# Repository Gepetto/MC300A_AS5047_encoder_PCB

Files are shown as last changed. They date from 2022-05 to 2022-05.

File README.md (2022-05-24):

# MC300_AS5047_encoder_PCB
This is a PCB support for a AS5047 magnetic encoder to replace MC300A control board on myactuator RMD-X actuators.



https://ams.com/en/as5047p
https://www.myactuator.com/_files/ugd/cab28a_d12405ad9d114c308658ca2bf5e42c5b.pdf

# Authors 
* Amine El Hamdaoui
* Jerome Manhes
* Thomas Flayols

LAAS CNRS

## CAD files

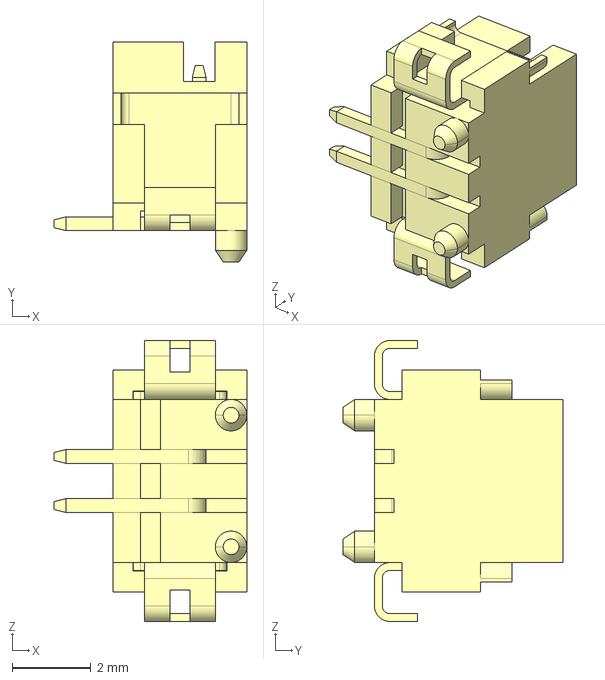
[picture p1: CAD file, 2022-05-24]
encoder_PCB/3D Models/DF13-2P-1.25V-75---3DModel-STEP-1.STEP
4.90 x 5.60 x 7.15 mm

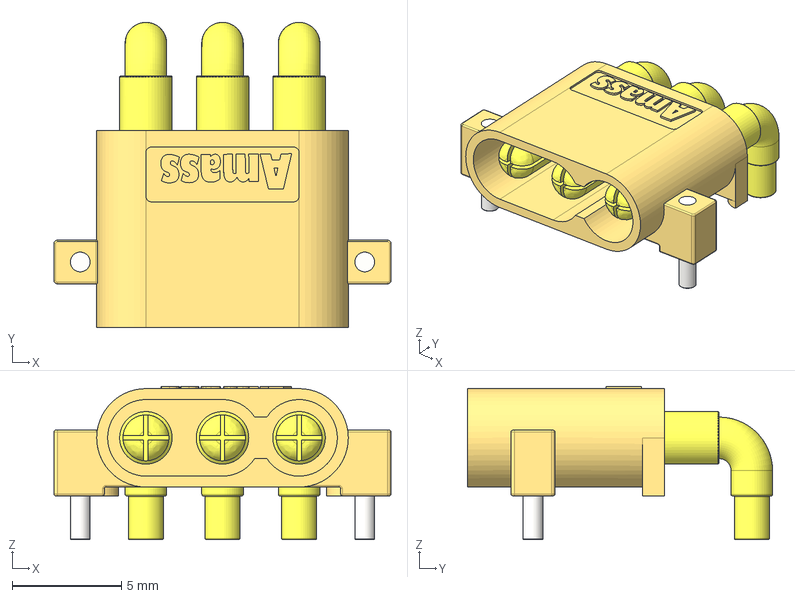
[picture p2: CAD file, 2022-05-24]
encoder_PCB/symbols_blueprints_3D_backup/MR30PW-M v2.step
15.4 x 13.9 x 7.00 mm
PCB Pins
Pin 2 x 3

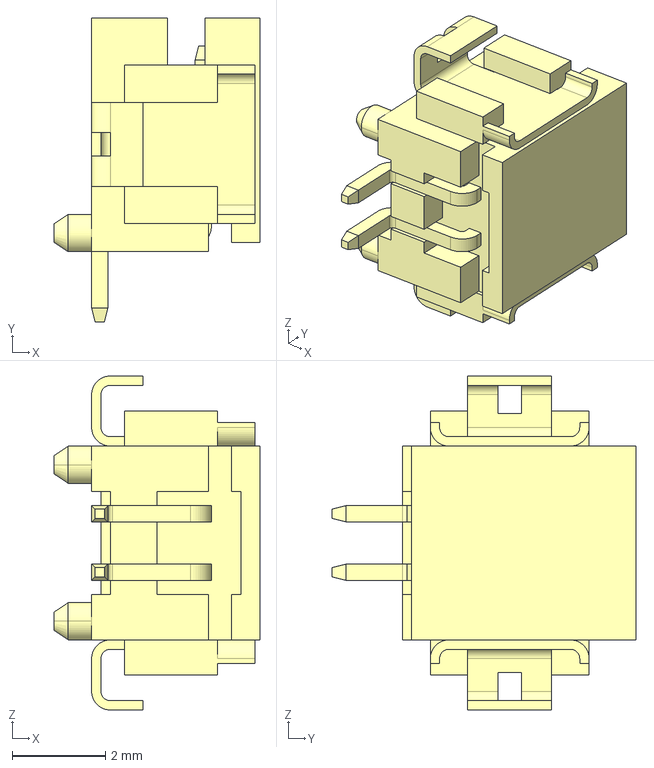
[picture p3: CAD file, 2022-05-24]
encoder_PCB/3D Models/DF13-2P-1.25H-75---3DModel-STEP-1.STEP
4.40 x 6.50 x 7.15 mm

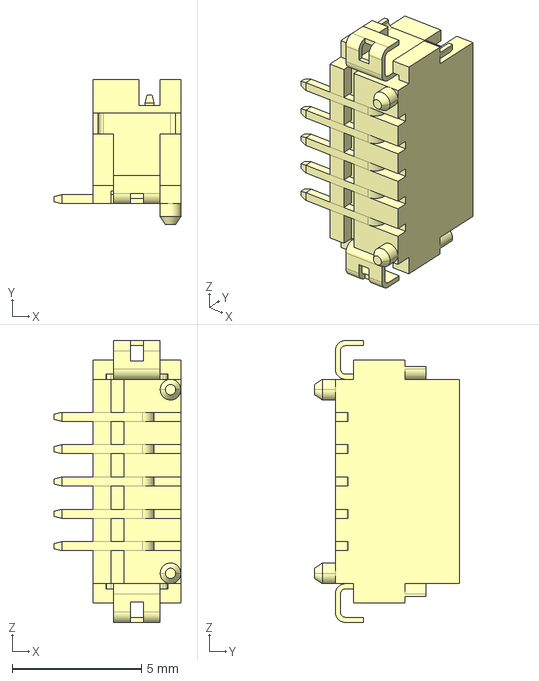
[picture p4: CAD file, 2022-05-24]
encoder_PCB/symbols_blueprints_3D_backup/DF13-5P-1.25V_75_.step
4.90 x 5.60 x 10.9 mm

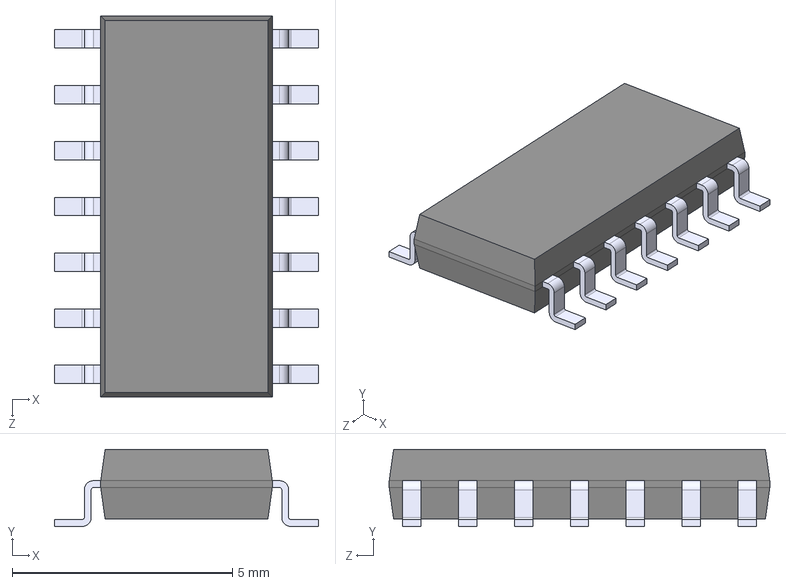
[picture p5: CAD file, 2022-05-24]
encoder_PCB/3D Models/SN74LV125AD.step
6.00 x 1.75 x 8.65 mm

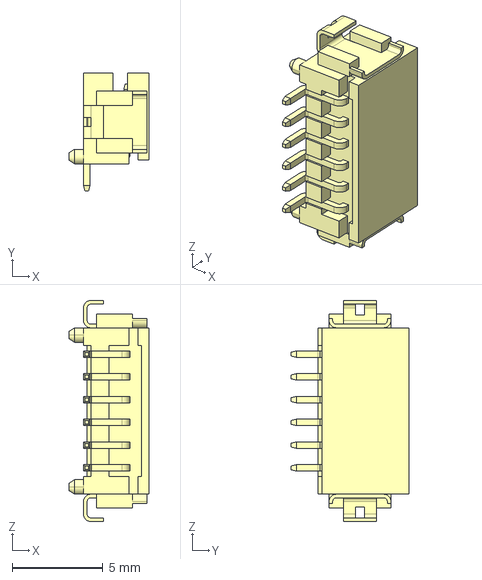
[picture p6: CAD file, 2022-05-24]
encoder_PCB/symbols_blueprints_3D_backup/DF13-6P-1.25H--3DModel-STEP-1.STEP
4.40 x 6.50 x 12.1 mm

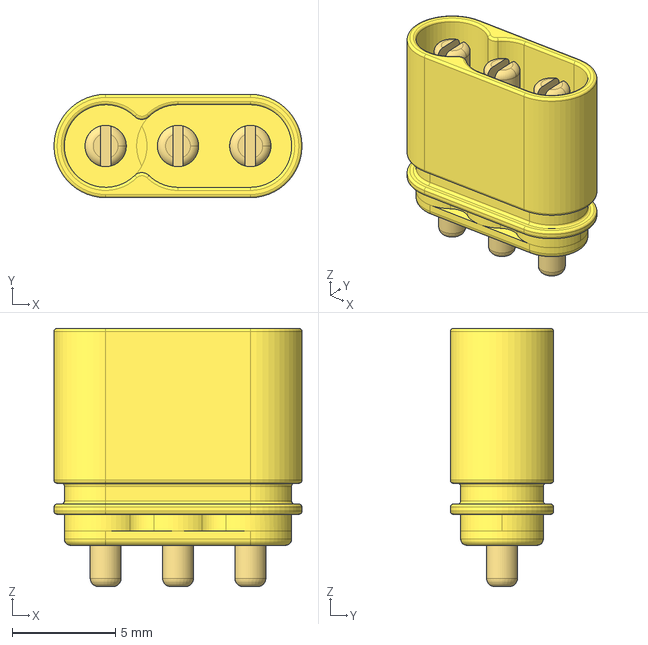
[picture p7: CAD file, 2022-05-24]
encoder_PCB/symbols_blueprints_3D_backup/Amass_MR30PB-M.step
12.0 x 5.00 x 12.5 mm

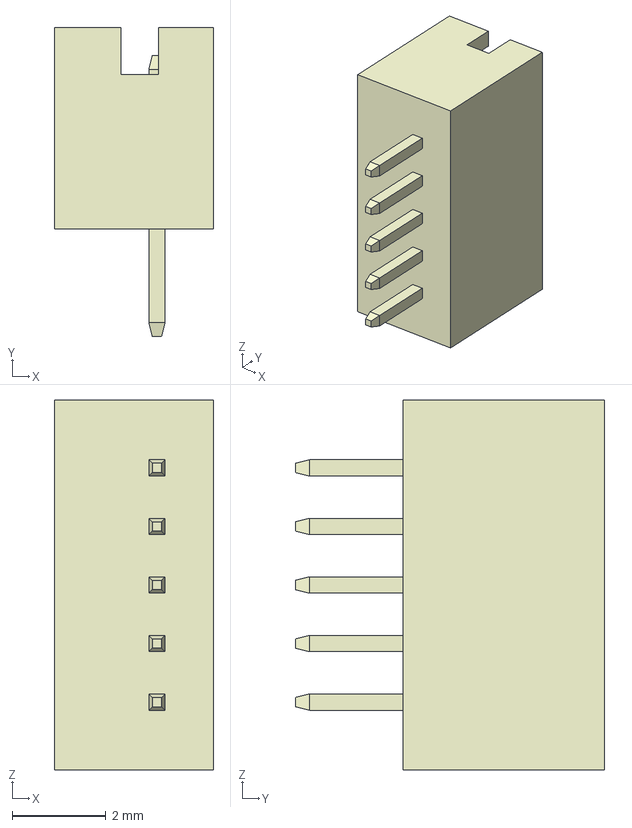
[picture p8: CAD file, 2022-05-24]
encoder_PCB/3D Models/DF13-5P-1.25DSA.step
3.40 x 6.60 x 7.90 mm

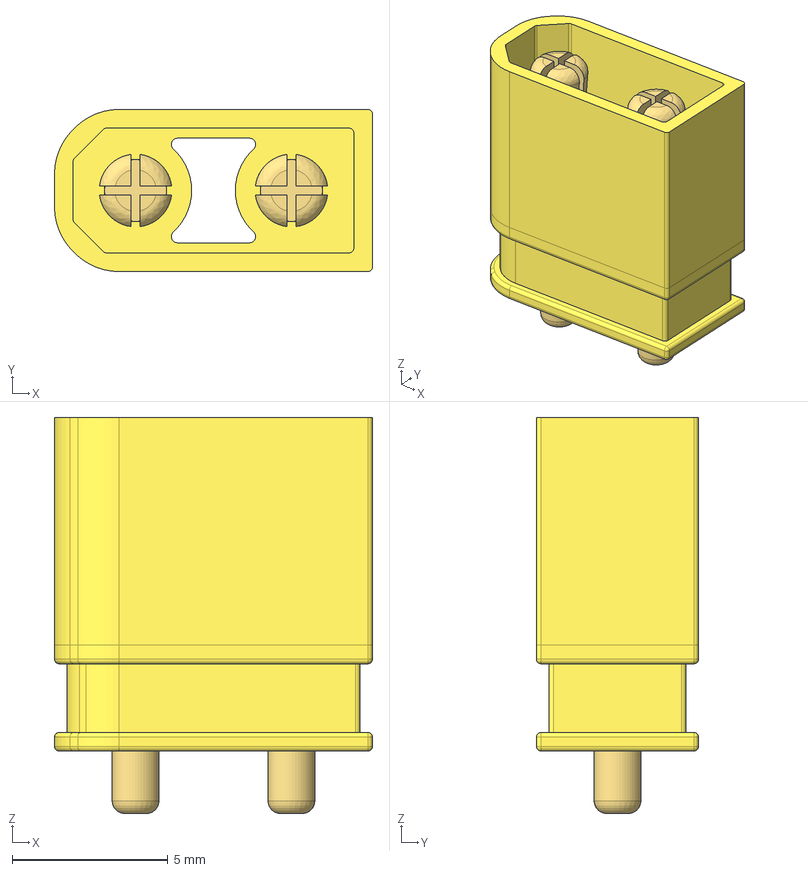
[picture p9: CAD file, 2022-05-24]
encoder_PCB/symbols_blueprints_3D_backup/Amass_XT30UPB-M.step
10.2 x 5.20 x 12.7 mm

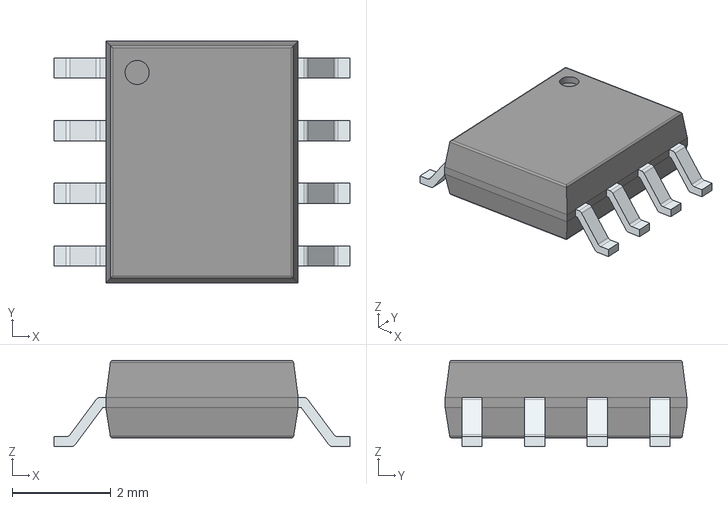
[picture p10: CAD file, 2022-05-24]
encoder_PCB/3D Models/NE555DR.stp
6.00 x 4.90 x 1.75 mm
PinsArrayLR

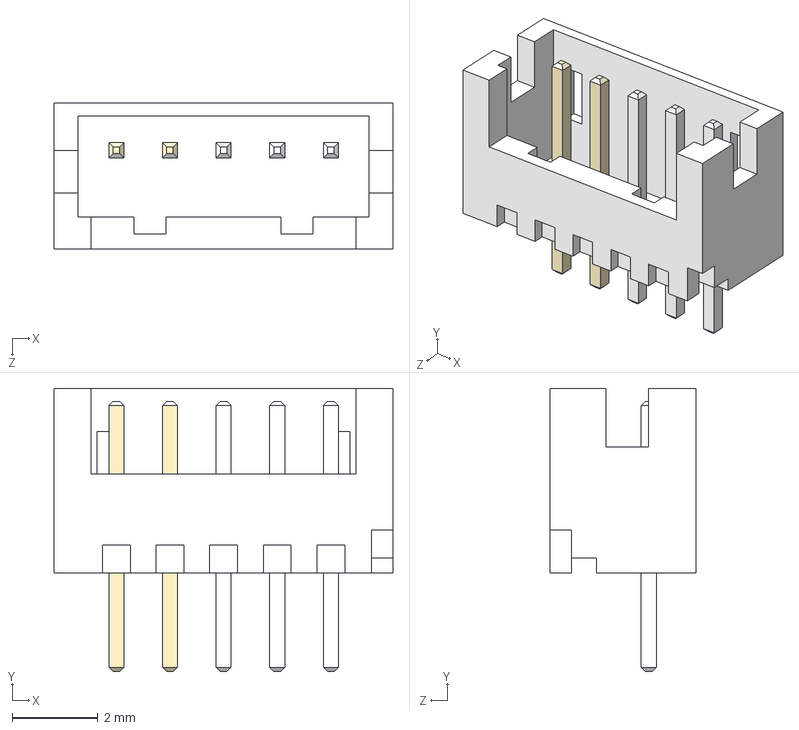
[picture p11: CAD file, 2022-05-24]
encoder_PCB/3D Models/DF13-5P-1.25DSA(50).STEP
7.90 x 6.60 x 3.40 mm

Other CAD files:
encoder_PCB/3D Models/AS5047U-HTSM.stp

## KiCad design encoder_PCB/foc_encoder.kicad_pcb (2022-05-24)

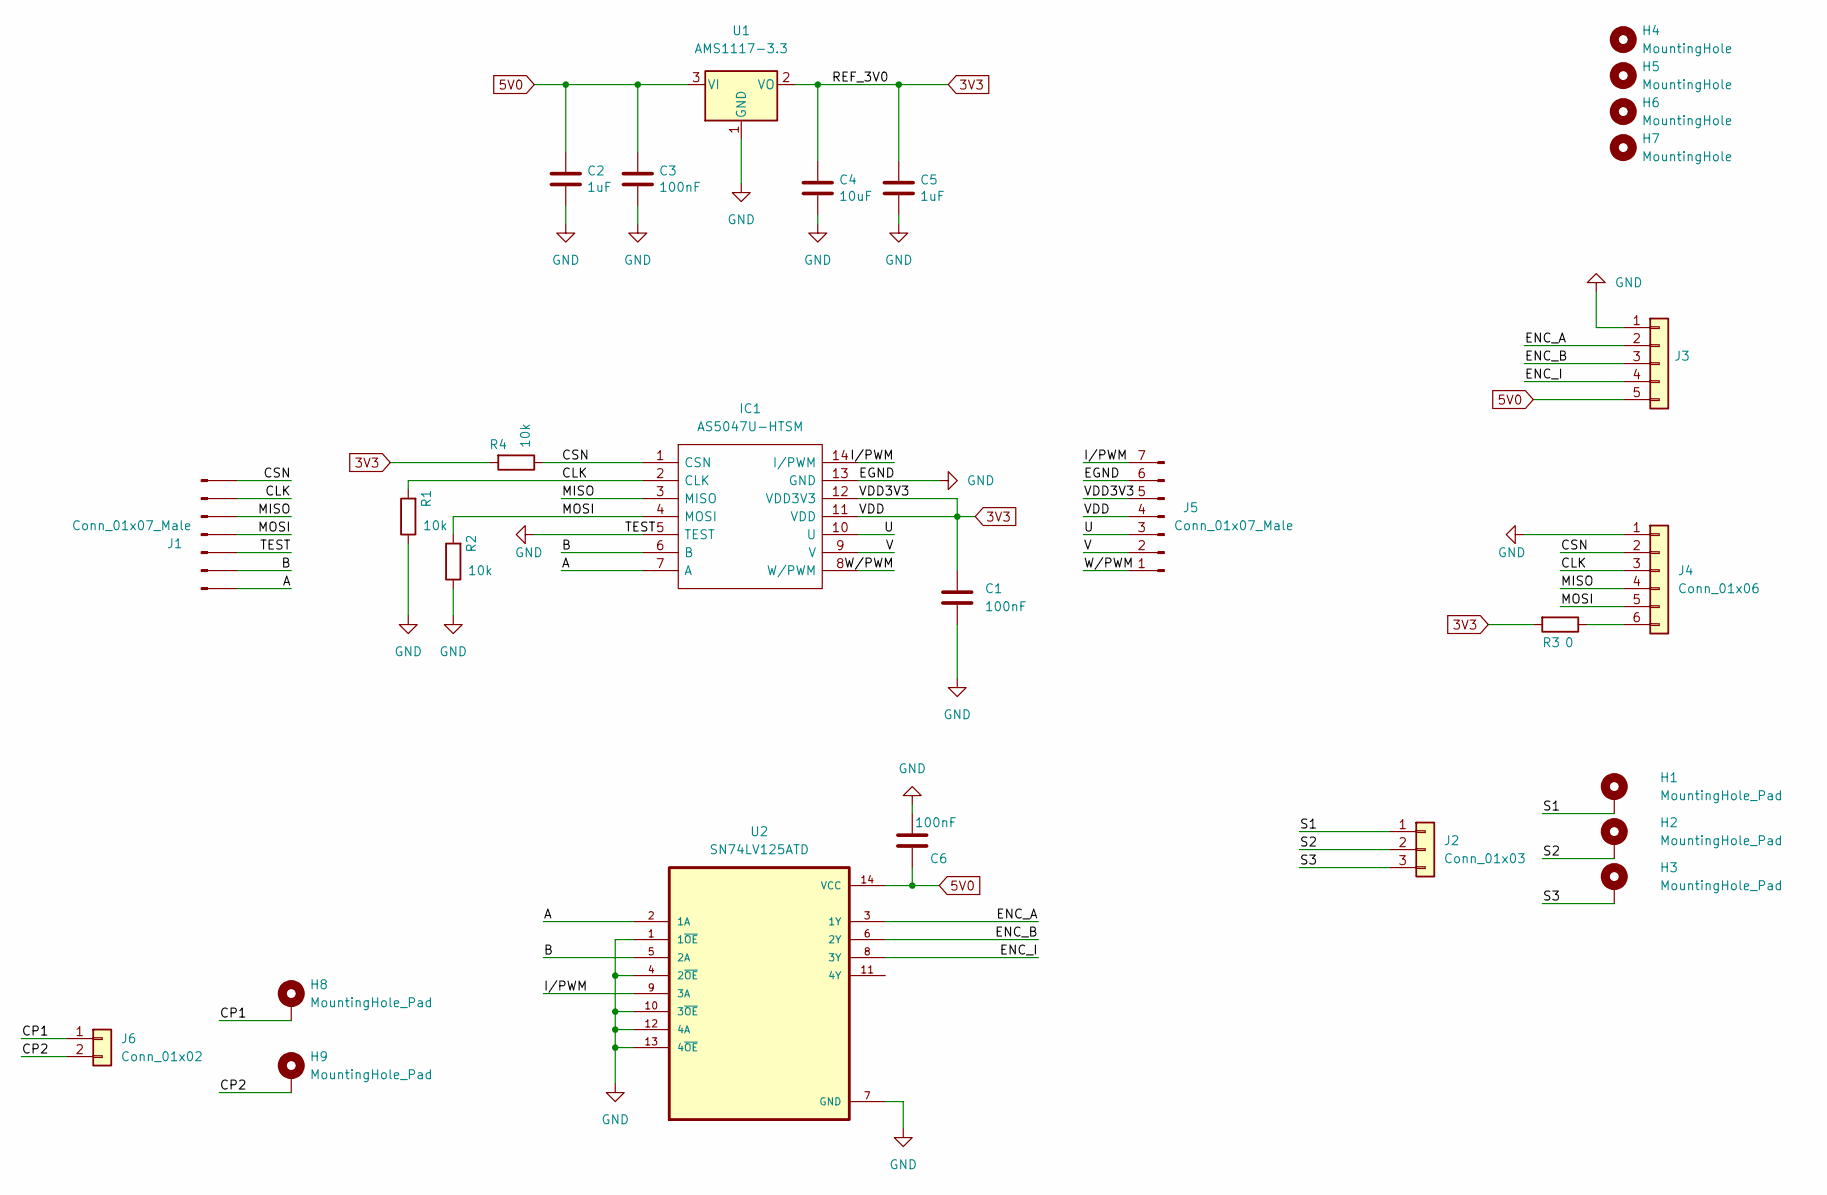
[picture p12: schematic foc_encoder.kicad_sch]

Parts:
C1, C6: 100nF; C_0402_1005Metric
C2, C5: 1uF; C_0402_1005Metric; Rated Voltage 10V; Part No GRM033C81A105ME05D; DigiKey 490-13219-1-ND
C3: 100nF; C_0402_1005Metric; Rated Voltage 10V; Part No GRM033R61E104KE14J; DigiKey 490-14571-1-ND
C4: 10uF; C_0402_1005Metric; Rated Voltage 10V; Part No GRM188R61A106ME69D; DigiKey 490-10475-1-ND
H1, H2, H3, H8, H9: MountingHole_Pad; MountingHole_2.2mm_M2_Pad
H4, H5, H6, H7: MountingHole; MountingHole_2.2mm_M2
IC1: AS5047U-HTSM; SOP65P640X110-14N; Manufacturer_Part_Number AS5047U-HTSM; Mouser Part Number 985-AS5047U-HTSM
J1, J5: Conn_01x07_Male; PinHeader_1x07_P2.54mm_Vertical
J2: Conn_01x03; AMASS_MR30PW-M_1x03_P3.50mm_Horizontal
J3: Hirose_DF13-05P-1.25DSA_1x05_P1.25mm_Vertical; Part No DF13-5P-1.25DSA; DigiKey H2194-ND
J4: Conn_01x06; Hirose_DF13-06P-1.25DSA_1x06_P1.25mm_Vertical
J6: Conn_01x02; Hirose_DF13-02P-1.25DSA_1x02_P1.25mm_Vertical
R1, R2, R4: 10k; R_0402_1005Metric
R3: 0; R_0402_1005Metric
U1: AMS1117-3.3; SOT-223-3_TabPin2
U2: SN74LV125ATD; SOIC127P600X175-14N

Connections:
3V3: C1.1, C4.1, C5.1, IC1.11 (VDD), IC1.12 (VDD3V3), J5.4, J5.5, R3.2, R4.2, U1.2 (VO)
5V0: C2.1, C3.1, C6.1, J3.5, U1.3 (VI), U2.14 (VCC)
/A: IC1.7 (A), J1.7, U2.2 (1A)
/B: IC1.6 (B), J1.6, U2.5 (2A)
/CLK: IC1.2 (CLK), J1.2, J4.3, R1.2
/CP1: H8.1, J6.1
/CP2: H9.1, J6.2
/CSN: IC1.1 (CSN), J1.1, J4.2, R4.1
/ENC_A: J3.2, U2.3 (1Y)
/ENC_B: J3.3, U2.6 (2Y)
/ENC_I: J3.4, U2.8 (3Y)
/I/PWM: IC1.14 (I/PWM), J5.7, U2.9 (3A)
/MISO: IC1.3 (MISO), J1.3, J4.4
/MOSI: IC1.4 (MOSI), J1.4, J4.5, R2.2
/S1: H1.1, J2.1
/S2: H2.1, J2.2
/S3: H3.1, J2.3
/U: IC1.10 (U), J5.3
/V: IC1.9 (V), J5.2
/W/PWM: IC1.8 (W/PWM), J5.1
GND: C1.2, C2.2, C3.2, C4.2, C5.2, C6.2, IC1.5 (TEST), IC1.13 (GND), J1.5, J3.1, J4.1, J5.6, R1.1, R2.1, U1.1 (GND), U2.1 (1~OE), U2.4 (2~OE), U2.7 (GND), U2.10 (3~OE), U2.12 (4A), U2.13 (4~OE)
unnamed: J4.6, R3.1

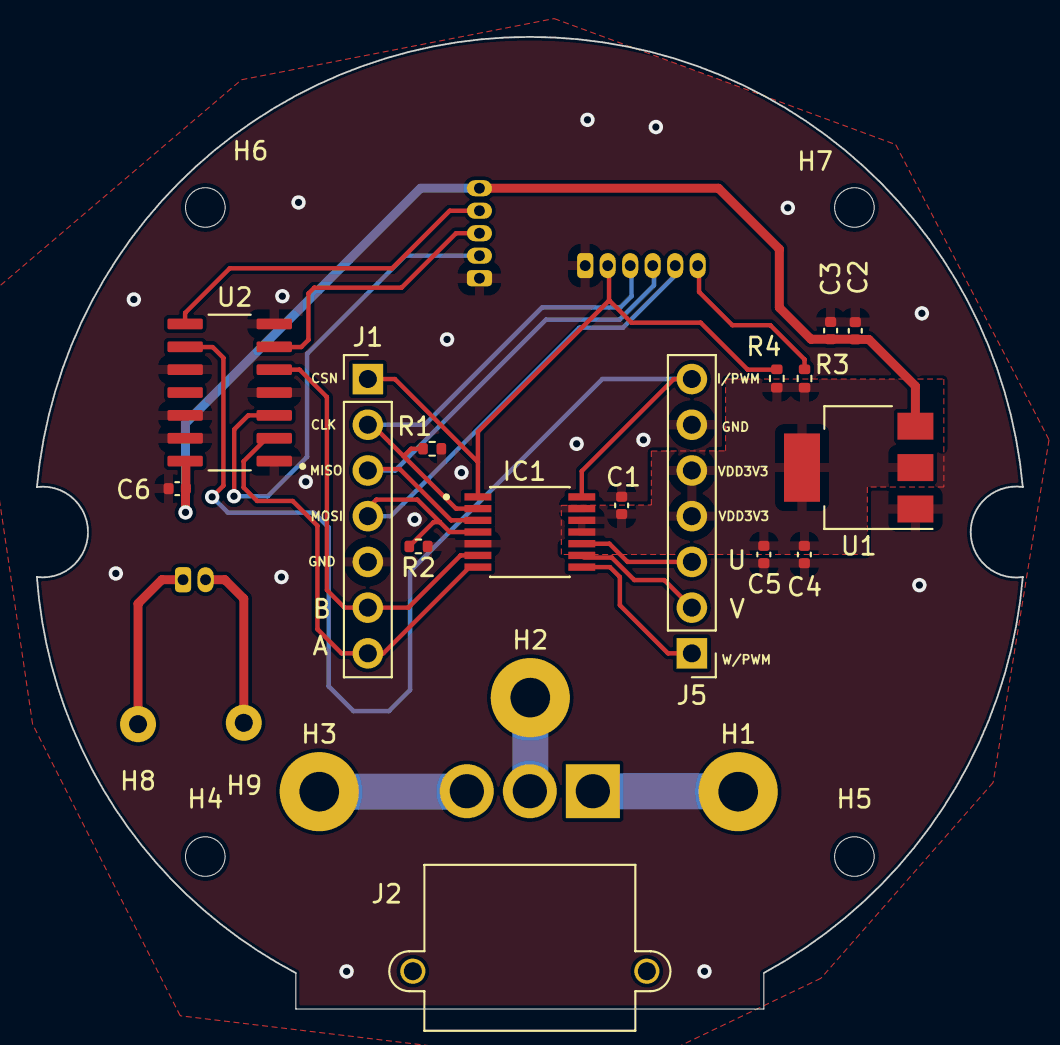
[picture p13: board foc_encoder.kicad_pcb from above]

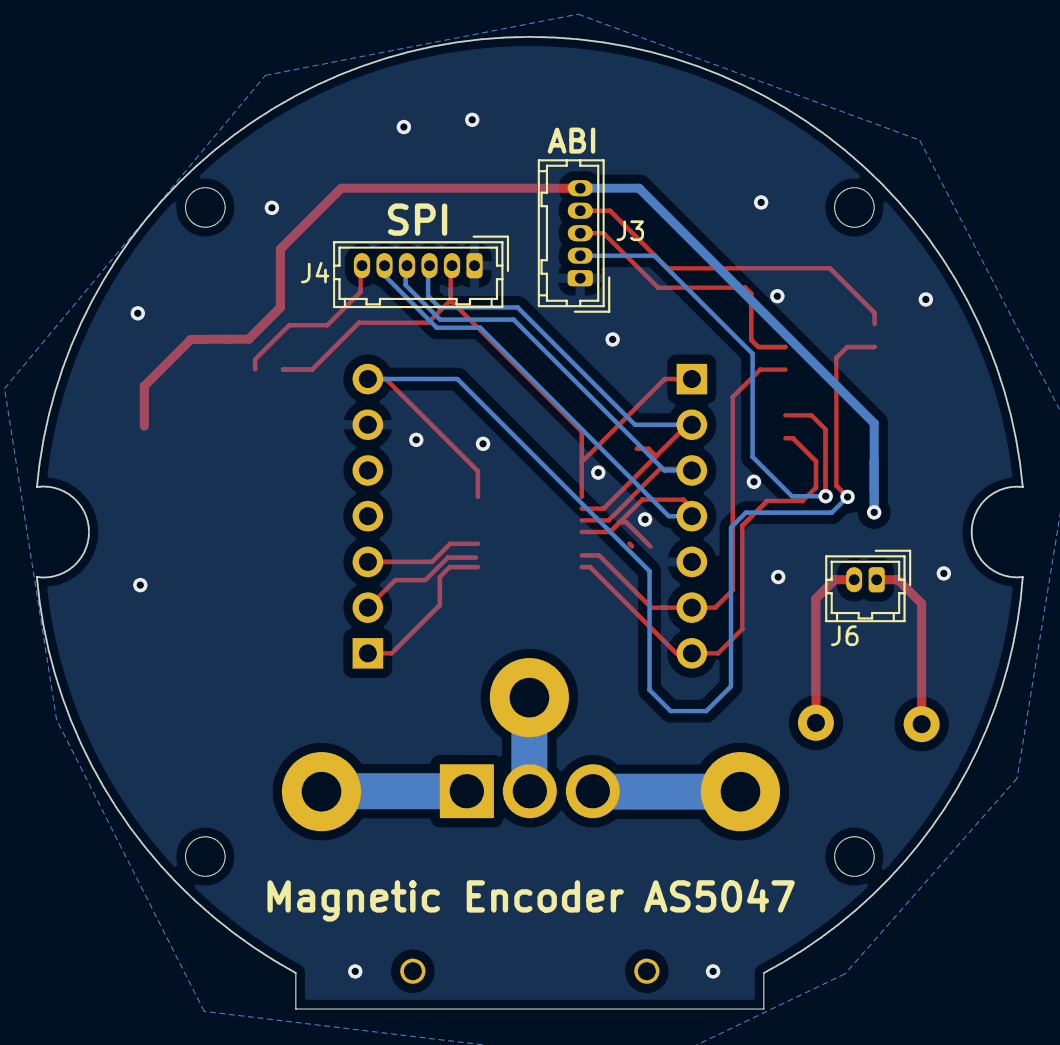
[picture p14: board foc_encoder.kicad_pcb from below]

Board: 2 copper layers, 54.8 x 54.0 mm, 28 parts (3 on the bottom side), 22 nets.

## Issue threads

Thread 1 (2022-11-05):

Anyway to order these

1Plus2Equals3D, 2022-11-05:
Hey! Thanks for the awesome design. We have had nothing but badluck with the driver included with these motors and would love to switch to a odrive so spotting your encoder/power board was a godsend.

Anyway to order these?

thomasfla, 2022-11-05:
Hi,
This design is open source, don't hesitate to send the design to a PCB manufacturer to replicate the design.

Best,
Thomas
